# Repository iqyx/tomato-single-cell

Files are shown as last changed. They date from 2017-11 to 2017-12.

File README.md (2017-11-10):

A single cell Li-Ion/Li-Po/LiFePO4 MPPT solar charger
===========================================================

Roadmap for the 1.0.0 firmware
-------------------------------------

- fw: enable setting of the solar panel MPP voltage
- fw: enable setting of the battery float voltage (3.6V/4.2V)
- fw: enable setting of the battery UVLO
- fw: save the settings in a nonvolatile storage
- fw: locking/unlocking settings which may cause damage (battery voltages, etc.)

Firmware changelog (1.0.0-dev)
-------------------------------------

- fw: added I2C timeouts to fix communication errors with the STC3100 battery gauge/monitor
- fw: interface was changed to protocol buffers (using the nanopb library) and defined as a proto file
- fw: firmware has been split into multiple files
- fw: added IWDG watchdog
- fw: added undervoltage shutdown for the Vbus converter (hardcoded now)
- fw: added NTC battery temperature reading

TODO
------------

- fw: add periodic scan of the Vin_reg to fnd an optimal MPP voltage
- fw: add perturb and observe algo for setting of the MPP voltage
- fw: add status led
- fw: add stop mode when not charging (PWM is off)

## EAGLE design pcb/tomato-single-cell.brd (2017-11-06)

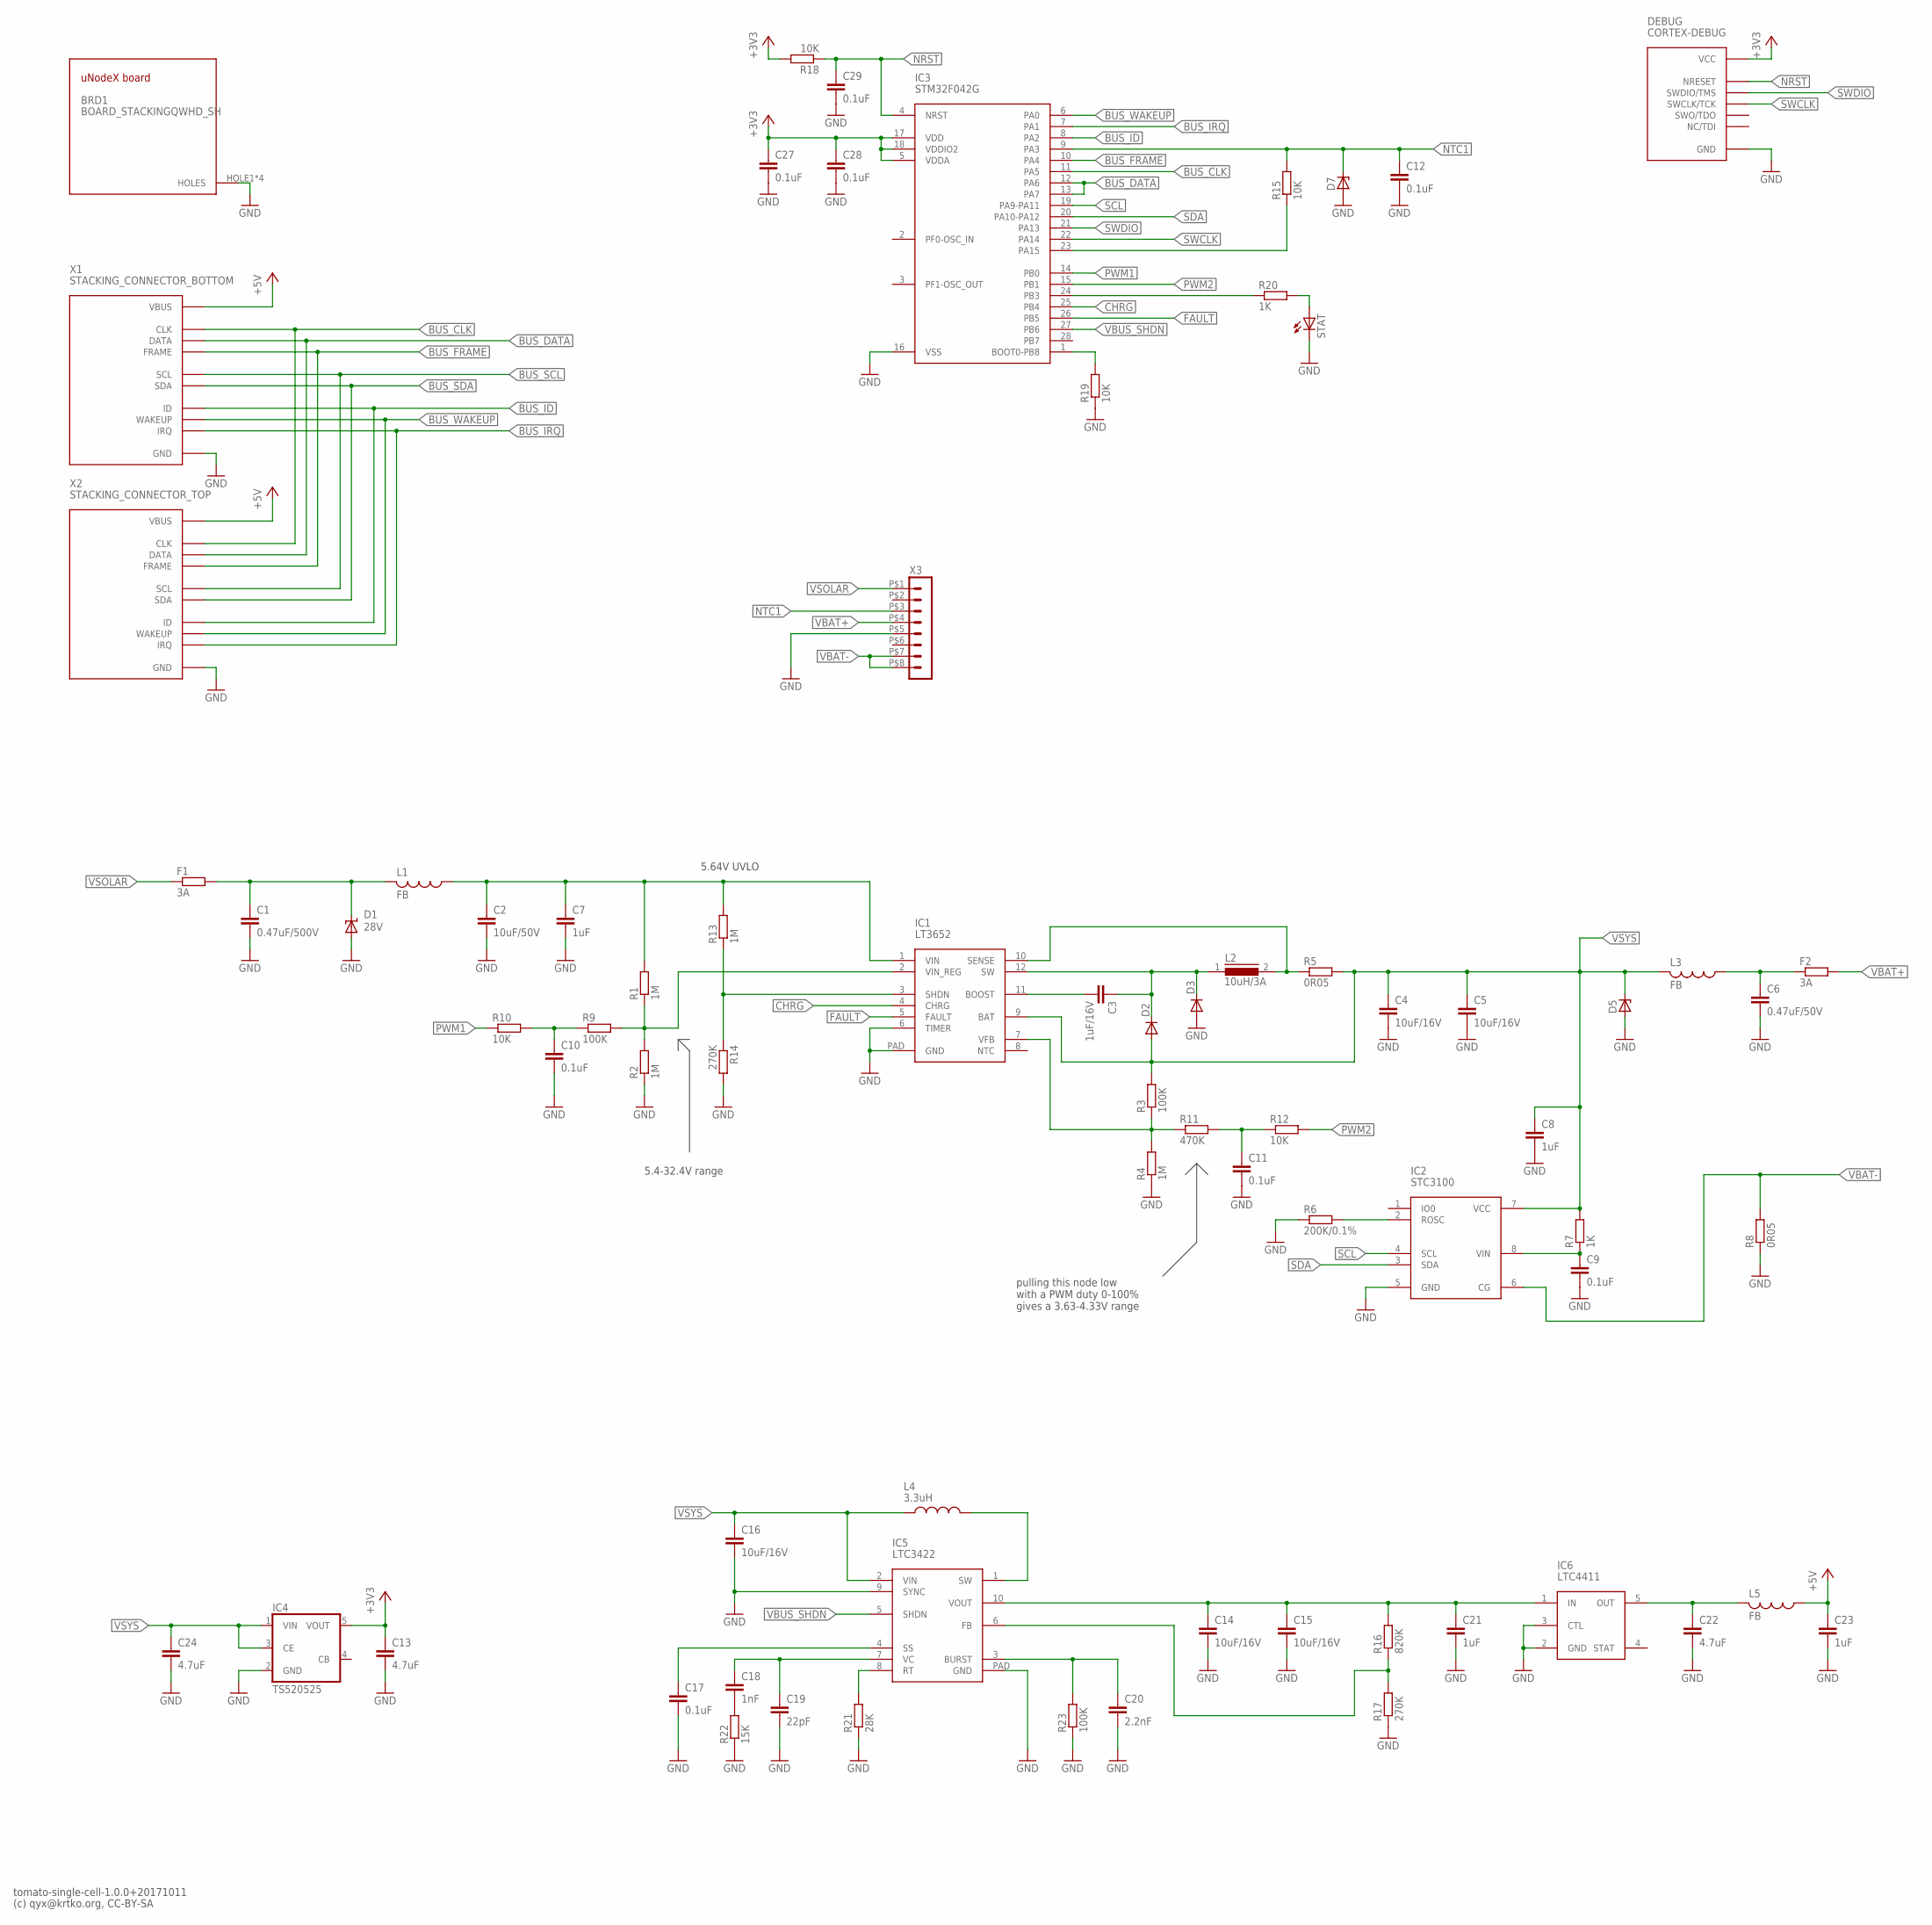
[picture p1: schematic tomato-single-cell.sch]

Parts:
BRD1: BOARD_STACKINGQWHD_SH; QWHD_SHARP_CORNERS
C1: 0.47uF/500V; C1206
C2: 10uF/50V; C2220K
C3: 1uF/16V; C0805
C4, C5, C14, C15, C16: 10uF/16V; C1206
C6: 0.47uF/50V; C0805
C7, C21, C23: 1uF; C0805
C8: 1uF; C0603
C9, C10, C11, C12, C17, C27, C28, C29: 0.1uF; C0603
C13, C22, C24: 4.7uF; C0805
C18: 1nF; C0603
C19: 22pF; C0603
C20: 2.2nF; C0603
D1: 28V; SMBJ
D2, D3: DIODE-SOD323-W; SOD323-W
D5, D7: ZENER-DIODESOT23; SOT23
DEBUG: CORTEX-DEBUG
F1, F2: 3A; R1206
IC1: LT3652; MSOP12-PAD
IC2: STC3100; MSOP8
IC3: STM32F042G; UFQFPN28
IC4: TS520525; SOT25
IC5: LTC3422; DFN10-3X3
IC6: LTC4411; SOT23-5
L1, L3, L5: FB; L3216C
L2: 10uH/3A; DR74
L4: 3.3uH; XAL50XX
R1, R2, R4, R13: 1M; R0603
R3, R9, R23: 100K; R0603
R5, R8: 0R05; R1206
R6: 200K/0.1%; R0603
R7, R20: 1K; R0603
R10, R12, R15, R18, R19: 10K; R0603
R11: 470K; R0603
R14, R17: 270K; R0603
R16: 820K; R0603
R21: 28K; R0603
R22: 15K; R0603
STAT: LEDCHIPLED_0805; CHIPLED_0805
X1: STACKING_CONNECTOR_BOTTOM; HAR-FLEX-BOTTOM-12P
X2: STACKING_CONNECTOR_TOP; HAR-FLEX-TOP-12P
X3: HEADER_POS8_43045-0800; 43045-0800

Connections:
+3V3: C13.1, C27.1, C28.1, DEBUG.VCC, IC3.5 (VDDA), IC3.17 (VDD), IC3.18 (VDDIO2), IC4.5 (VOUT), R18.2
+5V: C23.1, L5.1, X1.VBUS, X2.VBUS
BUS_CLK: IC3.11 (PA5), X1.CLK, X2.CLK
BUS_DATA: IC3.12 (PA6), IC3.13 (PA7), X1.DATA, X2.DATA
BUS_FRAME: IC3.10 (PA4), X1.FRAME, X2.FRAME
BUS_ID: IC3.8 (PA2), X1.ID, X2.ID
BUS_IRQ: IC3.7 (PA1), X1.IRQ, X2.IRQ
BUS_SCL: X1.SCL, X2.SCL
BUS_SDA: X1.SDA, X2.SDA
BUS_WAKEUP: IC3.6 (PA0), X1.WAKEUP, X2.WAKEUP
CHRG: IC1.4 (CHRG), IC3.25 (PB4)
FAULT: IC1.5 (FAULT), IC3.26 (PB5)
GND: BRD1.HOLE1, BRD1.HOLE2, BRD1.HOLE3, BRD1.HOLE4, C1.2, C2.2, C4.2, C5.2, C6.2, C7.2, C8.2, C9.2, C10.2, C11.2, C12.2, C13.2, C14.2, C15.2, C16.2, C17.2, C19.2, C20.2, C21.2, C22.2, C23.2, C24.2, C27.2, C28.2, C29.2, D1.A, D3.A, D5.1 (A), D7.1 (A), DEBUG.GND1 (GND), DEBUG.GND2 (GND), DEBUG.GND_DETECT (GND), IC1.6 (TIMER), IC1.PAD (GND), IC2.5 (GND), IC3.16 (VSS), IC4.2 (GND), IC5.9 (SYNC), IC5.PAD (GND), IC6.2 (GND), IC6.3 (CTL), R2.1, R4.1, R6.1, R8.1, R14.2, R17.1, R19.1, R21.1, R22.1, R23.1, STAT.C, X1.GND1 (GND), X1.GND2 (GND), X1.GND3 (GND), X1.H1 (GND), X1.H2 (GND), X1.H3 (GND), X1.H4 (GND), X2.GND1 (GND), X2.GND2 (GND), X2.GND3 (GND), X2.H1 (GND), X2.H2 (GND), X2.H3 (GND), X2.H4 (GND), X3.P$5 (5)
unnamed: C1.1, D1.C, F1.2, L1.2
unnamed: IC2.2 (ROSC), R6.2
unnamed: IC1.2 (VIN_REG), R1.1, R2.2, R9.2
unnamed: C9.1, IC2.8 (VIN), R7.1
unnamed: C10.1, R9.1, R10.2
unnamed: C11.1, R11.2, R12.1
unnamed: IC1.3 (SHDN), R13.1, R14.1
unnamed: C3.1, D2.C, D3.C, IC1.12 (SW), L2.1
unnamed: C17.1, IC5.4 (SS)
unnamed: C3.2, IC1.11 (BOOST)
unnamed: IC1.10 (SENSE), L2.2, R5.1
unnamed: IC1.7 (VFB), R3.1, R4.2, R11.1
unnamed: IC3.23 (PA15), R15.1
unnamed: IC3.24 (PB3), R20.1
unnamed: IC5.1 (SW), L4.2
unnamed: C14.1, C15.1, C21.1, IC5.10 (VOUT), IC6.1 (IN), R16.2
unnamed: IC5.6 (FB), R16.1, R17.2
unnamed: IC5.8 (RT), R21.2
unnamed: C18.2, R22.2
unnamed: C18.1, C19.1, IC5.7 (VC)
unnamed: C20.1, IC5.3 (BURST), R23.2
unnamed: C22.1, IC6.5 (OUT), L5.2
unnamed: IC3.1 (BOOT0-PB8), R19.2
unnamed: R20.2, STAT.A
NRST: C29.1, DEBUG.NRESET, IC3.4 (NRST), R18.1
NTC1: C12.1, D7.3 (C), IC3.9 (PA3), R15.2, X3.P$3 (3)
PWM1: IC3.14 (PB0), R10.1
PWM2: IC3.15 (PB1), R12.2
SCL: IC2.4 (SCL), IC3.19 (PA9-PA11)
SDA: IC2.3 (SDA), IC3.20 (PA10-PA12)
SWCLK: DEBUG.SWCLK/TCK, IC3.22 (PA14)
SWDIO: DEBUG.SWDIO/TMS, IC3.21 (PA13)
VBAT+: F2.2, X3.P$4 (4)
VBAT+PO: C6.1, F2.1, L3.1
VBAT-: IC2.6 (CG), R8.2, X3.P$7 (7), X3.P$8 (8)
VBUS_SHDN: IC3.27 (PB6), IC5.5 (SHDN)
VIN: C2.1, C7.1, IC1.1 (VIN), L1.1, R1.2, R13.2
VSOLAR: F1.1, X3.P$1 (1)
VSYS: C4.1, C5.1, C8.1, C16.1, C24.1, D2.A, D5.3 (C), IC1.9 (BAT), IC2.7 (VCC), IC4.1 (VIN), IC4.3 (CE), IC5.2 (VIN), L3.2, L4.1, R3.2, R5.2, R7.2

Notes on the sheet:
tomato-single-cell-1.0.0+20171011
(c) qyx@krtko.org, CC-BY-SA
pulling this node low with a PWM duty 0-100% gives a 3.63-4.33V range
5.4-32.4V range
5.64V UVLO

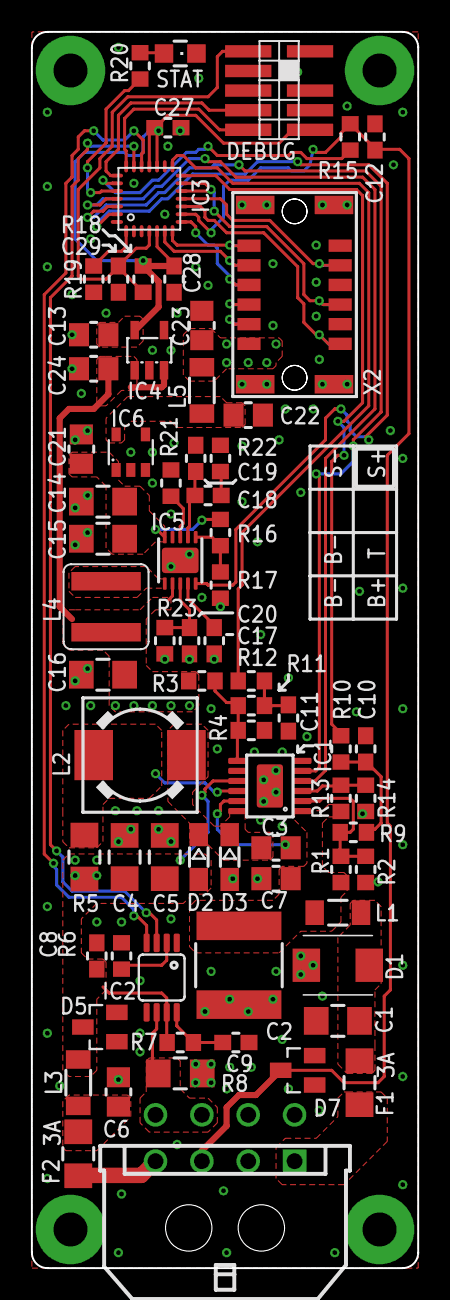
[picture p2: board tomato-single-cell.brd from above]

Board: 2 copper layers, 25.0 x 80.0 mm, 74 parts (0 on the bottom side), 52 nets.

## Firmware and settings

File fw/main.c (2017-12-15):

/*
 * tomato-series single cell LiFePo4/Li-Ion charger firmware
 *
 * Copyright (C) 2017, Marek Koza, qyx@krtko.org
 *
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
 * You should have received a copy of the GNU General Public License
 * along with this program.  If not, see <http://www.gnu.org/licenses/>.
 */

#include <stdio.h>
#include <string.h>
#include <stdio.h>
#include <stdbool.h>

#include <libopencm3/stm32/rcc.h>
#include <libopencm3/stm32/gpio.h>
#include <libopencm3/stm32/iwdg.h>

#include "uxb_slave.h"
#include "battery_monitor.h"
#include "voltage_control.h"
#include "ntc.h"


#define LED_PORT GPIOB
#define LED_PIN GPIO3


/* Semihosting. */
extern void initialise_monitor_handles(void);


static void clock_setup(void) {
	/* No prediv, running at the full 8MHz HSI speed. */
	rcc_set_hpre(RCC_CFGR_HPRE_DIV8);
	rcc_periph_clock_enable(RCC_GPIOA);
	rcc_periph_clock_enable(RCC_GPIOB);
}


/* GPIO initialization which does not fit elsewere. */
static void gpio_setup(void) {
	/* Initialize the STAT LED. */
	gpio_mode_setup(LED_PORT, GPIO_MODE_OUTPUT, GPIO_PUPD_NONE, LED_PIN);
}


static void watchdog_setup(void) {
	iwdg_set_period_ms(5000);
	iwdg_start();
}


int main(void) {

	clock_setup();
	watchdog_setup();
	// initialise_monitor_handles();
	gpio_setup();
	uxb_slave_init();
	stc3100_init();
	ntc_init();
	uvlo_init();
	uvlo_set(3300, 3500);
	voltage_control_init();
	voltage_control_set_vin_reg(10000);
	voltage_control_set_vbat(4100);

	while (1) {
		/* Blink the LED just for the lulz. */
		gpio_set(LED_PORT, LED_PIN);
		for (uint32_t i = 0; i < 1000; i++) {
			__asm__("nop");
		}
		gpio_clear(LED_PORT, LED_PIN);
		for (uint32_t i = 0; i < 100000; i++) {
			__asm__("nop");
		}

		/** @todo read by a periodic timer interrupt */
		stc3100_read();
		uvlo_check();
		ntc_read();
		iwdg_reset();
	}

	return 0;
}

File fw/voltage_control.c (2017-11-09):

/*
 * PWM control of the Vin_reg and Vfb resistor dividers
 *
 * Copyright (C) 2017, Marek Koza, qyx@krtko.org
 *
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
 * You should have received a copy of the GNU General Public License
 * along with this program.  If not, see <http://www.gnu.org/licenses/>.
 */

#include <stdint.h>

#include <libopencm3/cm3/nvic.h>
#include <libopencm3/stm32/rcc.h>
#include <libopencm3/stm32/gpio.h>
#include <libopencm3/stm32/timer.h>

#include "uxb_slave.h"
#include "voltage_control.h"


#define PWM_MAX 255

void voltage_control_init(void) {

	/* PWM outputs. */
	gpio_mode_setup(GPIOB, GPIO_MODE_AF, GPIO_PUPD_NONE, GPIO0 | GPIO1);
	gpio_set_output_options(GPIOB, GPIO_OTYPE_PP, GPIO_OSPEED_2MHZ, GPIO0 | GPIO1);
	gpio_set_af(GPIOB, GPIO_AF1, GPIO0 | GPIO1);

	/* Setup the timer used to control the PWM outputs. */
	rcc_periph_clock_enable(RCC_TIM3);
	timer_reset(TIM3);
	timer_set_mode(TIM3, TIM_CR1_CKD_CK_INT, TIM_CR1_CMS_EDGE, TIM_CR1_DIR_UP);
	timer_continuous_mode(TIM3);
	timer_direction_up(TIM3);
	timer_disable_preload(TIM3);
	timer_enable_update_event(TIM3);
	timer_set_prescaler(TIM3, 0);
	timer_set_period(TIM3, PWM_MAX);

	timer_disable_oc_preload(TIM3, TIM_OC3);
	timer_set_oc_mode(TIM3, TIM_OC3, TIM_OCM_PWM2);
	timer_set_oc_value(TIM3, TIM_OC3, 0);
	timer_enable_oc_output(TIM3, TIM_OC3);

	timer_disable_oc_preload(TIM3, TIM_OC4);
	timer_set_oc_mode(TIM3, TIM_OC4, TIM_OCM_PWM2);
	timer_set_oc_value(TIM3, TIM_OC4, 0);
	timer_enable_oc_output(TIM3, TIM_OC4);

	timer_enable_counter(TIM3);
}


void voltage_control_set_vin_reg(uint32_t vin_reg_mv) {

	/* Check the voltage range and calculate the pwm duty cycle value. */
	if (vin_reg_mv < 5400) {
		vin_reg_mv = 5400;
	}
	uint32_t pwm = (vin_reg_mv - 5400) * PWM_MAX / (29945 - 5400);
	if (pwm > PWM_MAX) {
		pwm = PWM_MAX;
	}

	timer_set_oc_value(TIM3, TIM_OC3, pwm);
}


void voltage_control_set_vbat(uint32_t vbat_mv) {

	if (vbat_mv < 3630) {
		vbat_mv = 3630;
	}
	uint32_t pwm = (vbat_mv - 3630) * PWM_MAX / (4320 - 3630);
	if (pwm > PWM_MAX) {
		pwm = PWM_MAX;
	}

	timer_set_oc_value(TIM3, TIM_OC4, pwm);
}


uint32_t voltage_control_get_vin_reg_mv(void) {
	return 0;
}


uint32_t voltage_control_get_vbat_mv(void) {
	return 0;
}

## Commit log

2017-11-06 Add a basic PoC firmware
    The firmware supports communication over the UXB bus and
    reading the STC3100 battery gauge/monitor registers to
    measure battery voltage, charging/discharging current,
    chip temperature and cumulated battery charge. Those values
    are exported over the bus in a simple way (no protobufs yet).
2017-11-06 Add schematic diagram and a board layout
    [tomato-single-cell.brd, tomato-single-cell.sch]
2017-11-06 Add Gerber exports (ready for seeedstudio)
    [tomato-single-cell.GBL, tomato-single-cell.GBO, tomato-single-cell.GBP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]
2017-11-10 Add battery NTC temperature reading and an UVLO function
2017-11-13 Run the MCU at 1MHz, switch to 8MHz on uxb request
2017-11-13 Fix uxb bus delay
    [uxb_locm3.c]
2017-12-15 Quick fix battery type to 1cell Li-Ion & add value watchdog
    [battery_monitor.c, main.c]

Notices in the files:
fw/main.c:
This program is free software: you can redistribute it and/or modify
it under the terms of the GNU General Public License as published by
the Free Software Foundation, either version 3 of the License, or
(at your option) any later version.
